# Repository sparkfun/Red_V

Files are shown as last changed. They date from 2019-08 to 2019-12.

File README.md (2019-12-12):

SparkFun RED-V RedBoard
============================

SparkFun RED-V RedBoard (https://www.sparkfun.com/products/15594)

*[SparkFun RED-V RedBoard (DEV-15594)](https://www.sparkfun.com/products/15594)*

The SparkFun RED-V (pronounced “red-five”) RedBoard is a low-cost, development board featuring the Freedom E310 SoC which brings with it the RISC-V instruction set architecture (ISA). What sets the RED-V RedBoard apart from the rest is the completely open-source approach from hardware to ISA. That means anyone can make full use the microcontroller without requiring royalties, licenses, or non-disclosure agreements. 

The RED-V RedBoard comes in the familiar Arduino Uno R3 form factor and includes the SiFive Freedom E310 core, 32MB of QSPI flash, an NXP K22 ARM Cortex-M4 for USB connectivity and operating as a JTAG interface, and a Qwiic connector to make I<sup>2</sup>C easy. The modern USB-C connector makes it easy to program and for more advanced users who prefer to use the power and speed of professional tools, we've also exposed the JTAG connector. Additionally, it comes programmed with a simple bootloader making the RED-V the best way to start prototyping and developing your RISC‑V applications. 

The on board Freedom E310 (FE310) is the first member of the Freedom Everywhere family of customizable SoCs from SiFive. Designed for microcontroller, embedded, IoT, and wearable applications, the FE310 features SiFive’s E31 CPU Coreplex, a high-performance, 32-bit RV32IMAC core. Running at 320+ MHz, the FE310 is among the fastest microcontrollers in the market. Additional features include a 16KB L1 Instruction Cache, a 16KB Data SRAM scratchpad, hardware multiply/divide, a debug module, flexible clock generation with on-chip oscillators and PLLs, and a wide variety of peripherals including UARTs, QSPI, PWMs, and timers. Multiple power domains and a low-power standby mode ensure a wide variety of applications can benefit from the FE310. The RED-V requires Freedom Studio software or a Zephyr RTOS build environment set up to program the board and interface with it.

Repository Contents
-------------------
* **/Hardware** - Eagle design files (.brd, .sch)
* **/Production** - Production panel files (.brd)

Documentation
--------------
* **[Hookup Guide](https://learn.sparkfun.com/tutorials/red-v-redboard-hookup-guide)** - Basic hookup guide for the RedBoard.
* **[RED-V Development Guide](https://learn.sparkfun.com/tutorials/red-v-development-guide)** - Getting started with the RED-V in Freedom Studio and Zephyr RTOS.

License Information
-------------------

This product is _**open source**_! 

Please review the LICENSE.md file for license information. 

If you have any questions or concerns on licensing, please contact techsupport@sparkfun.com.

Distributed as-is; no warranty is given.

- Your friends at SparkFun.

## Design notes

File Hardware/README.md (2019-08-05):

SparkFun Redboard Design Files
=====================================

The .sch and .brd files hare are Eagle CAD schematic and PCB design files from SparkFun Electronics.
A freeware version of Eagle can be found [here](http://www.cadsoftusa.com/download-eagle/freeware/).

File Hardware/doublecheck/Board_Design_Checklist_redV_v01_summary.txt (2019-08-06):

1) Is the I2C pull-up resistor isolation jumper present? [NO]
comment: exists on qwiic slaves

2) Is the MISO tri-state buffer included? [NO]
comment: copying risc-v schematic

3) Are all QFN components with 6 or more leads 75 percent pasted on lead pads? (May be contended depending on performance) [NO]
comment: 48 qfn is known good

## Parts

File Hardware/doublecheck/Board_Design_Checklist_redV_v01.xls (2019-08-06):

SECTION | CHECK | STATUS | DEPENDANCY | CORRECT ANSWER | USER | USER-ANSWER | COMMENT | WIKI_LINK
Macro | is_revision | 0
Macro | has_pth | 0
Macro | has_i2c | 1
Macro | has_SPI | 1
Macro | has_1x6_ftdi_header | 0
Macro | has_jumpers | 0
Macro | has_leds | 1
Macro | has_vreg | 1
Macro | has_QFN | 1
Macro | has_SS | 0
Macro | has_multi_sheet | 0
Macro | is_kit | 0
Macro | has_serial | 0
Macro | is_4layer | 0
Macro | has_milling | 0
Macro | has_switchorbutton | 1
Macro | has_collaboration | 0
Schematic | Does the board pass the Schematic Autochecklist ULP? |  |  | YES
Schematic | Are all schematic objects inside the frame? |  |  | YES | andrew.england | YES
Schematic | Is proper attribution given to the original designer? |  |  | YES | andrew.england | YES
Schematic | Is "Revised by: " and the reviser's name present? |  | 2 | YES | andrew.england | *n/a*
Schematic | Have all nets been drawn straight out from pin connections at least one grid space? |  |  | YES | andrew.england | YES
Schematic | Are there any 4-way junctions? |  |  | NO | andrew.england | NO
Schematic | Are junction dots used for all 3-wire connections? |  |  | YES | andrew.england | YES
Schematic | Are the fiducials in the lower right corner? |  |  | YES | andrew.england | YES
Schematic | Are the standoffs in the lower right corner? |  |  | YES | andrew.england | YES
Schematic | Are dashed grey lines ('info' eagle layer 97) used to clearly separate different areas? |  |  | YES | andrew.england | YES
Schematic | Is the version number correct? |  |  | YES | andrew.england | YES
Schematic | Is the version number included on all sheets? |  | 12 | YES | andrew.england | *n/a*
Schematic | Do all GND connections use the GND symbol (oriented downward)? |  |  | YES | andrew.england | YES
Schematic | Do all VCC connections use the VCC symbol (oriented upward)? |  |  | YES | andrew.england | YES
Schematic | Is the VCC range clearly labeled? |  |  | YES | andrew.england | YES
Schematic | Are any jumpers labeled clearly by their function and possible settings? |  | 7 | YES | andrew.england | *n/a*
Schematic | Are any appropriate warnings (voltage conversion, sensitive I/O) labeled? |  |  | YES | andrew.england | YES
Schematic | Are any notes of two versions of the board in the schematic (3.3V regulator vs 5V regulator)? |  |  | YES | andrew.england | n/a
Schematic | Do any part names have '/.~' in them? (Multiple sheets) |  | 12 | NO | andrew.england | *n/a*
Schematic | Have you verified that the BOM *including PCB* (also checking for PROD_ID, NAME, VALUE, PREFIX)? |  |  | YES | andrew.england | YES
Schematic | Do any parts have unnecessary values (Eagle has autoset the package as the value)? |  |  | NO | andrew.england | NO
Schematic | Regarding the voltage regulator, is the input on the LEFT, and the output on the RIGHT? |  | 9 | YES | andrew.england | YES
Schematic | Is the I2C address in the schematic? |  | 4 | YES | andrew.england | n/a
Schematic | Is the I2C pin order correct (GND/VCC/SDA/CLK) and did you consider using a Qwiic connector? |  | 4 | YES | andrew.england | YES |  | https://wiki.sparkfun.com/index.php?title=Eagle_Rules#Pin_Out.2FConnection_Orientation
Schematic | Is the I2C pull-up resistor isolation jumper present? |  | 4 | YES | andrew.england | NO | exists on qwiic slaves | https://wiki.sparkfun.com/index.php?title=Eagle_Rules#Component_Placement
Schematic | Is the SPI pull-up resistor for Chip Select present? |  | 5 | YES | andrew.england | YES |  | https://wiki.sparkfun.com/index.php?title=Eagle_Rules#Component_Placement
Schematic | Is the MISO tri-state buffer included? |  | 5 | YES | andrew.england | NO | copying risc-v schematic | https://wiki.sparkfun.com/index.php?title=Eagle_Rules#Component_Placement
Board | Does the board pass the Board Autochecklist ULP? |  |  | YES | andrew.england | YES |  | https://wiki.sparkfun.com/index.php?title=Qwiic_Standard
Board | If this board is not branded as a Qwicc board, but contains a Qwiic connector, is the connector labeled with “QWIIC” text silk? |  | 4 | YES | andrew.england | YES
Board | Are the inner layers on the correct eagle layers? (2 and 15) |  | 15 | YES | andrew.england | *n/a* |  | https://wiki.sparkfun.com/index.php?title=Eagle_Rules#Board_Creation.2C_Outline
Board | Does your 4 layer board include '1' '2' '3' '4' in the copper of each layer? |  | 15 | YES | andrew.england | *n/a* |  | https://wiki.sparkfun.com/index.php?title=Eagle_Rules#Board_Creation.2C_Outline
Board | If this is a Qwiic board, does it follow the design guidelines for Qwiic boards in the Wiki? |  | 4 | YES | andrew.england | n/a |  | https://wiki.sparkfun.com/index.php?title=Eagle_Rules#Board_Creation.2C_Outline
Board | If this requires very precise dimensions (e.g. USB stick), did you consider GP's tolerances? (dimension=5mils, Vscore=10mils) |  |  |  | andrew.england | YES |  | https://wiki.sparkfun.com/index.php?title=Eagle_Rules#Fab_house_Tolerances
Board | Do all testpoints have a separation of at least 0.1 inch (preferably placed on a 0.05 inch grid)? |  |  | YES | andrew.england | YES |  | https://wiki.sparkfun.com/index.php?title=Eagle_Rules#Board_Creation.2C_Outline
Board | Can standoffs/screws be used clear of other parts? |  |  | YES | andrew.england | YES |  | https://wiki.sparkfun.com/index.php?title=Eagle_Rules#Board_Creation.2C_Outline
Board | Is the FTDI connector accessible (do neighboring parts allow enough space to clear each side)? |  | 6 | YES | andrew.england | *n/a* |  | https://wiki.sparkfun.com/index.php?title=Eagle_Rules#Pin_Out.2FConnection_Orientation
Board | Is the FTDI connector oriented so the FTDI breakout can be slid on properly (IC side up, header side down)? |  | 6 | YES | andrew.england | *n/a* |  | https://wiki.sparkfun.com/index.php?title=Eagle_Rules#Pin_Out.2FConnection_Orientation
Board | Are vias tented correctly? |  |  | YES | andrew.england | YES |  | https://wiki.sparkfun.com/index.php?title=Eagle_Rules#Trace_Routing.2C_Polygon_Pours.2C_and_Vias
Board | If possible, are all overhanging parts on the same edge of the board (this helps with panelization)? |  |  | YES | andrew.england | YES |  | https://wiki.sparkfun.com/index.php?title=Eagle_Rules#Pin_Out.2FConnection_Orientation
Board | If this design requires special ordering or production assembly instructions, have the symbols/packages been added with notes? (PCB thickness, humidity sensitivity, etc.) |  |  | YES | andrew.england | NO
Board | Are any vias intended to be used as PTH headers (they shouldn't be)? |  |  | NO | andrew.england | NO |  | https://wiki.sparkfun.com/index.php?title=Eagle_Rules#Trace_Routing.2C_Polygon_Pours.2C_and_Vias
Board | Is the LED color standard followed? (red for power, blue for STAT, green for TX, yellow for RX) |  | 8 | YES | andrew.england | YES |  | https://wiki.sparkfun.com/index.php?title=Eagle_Rules#Component_Placement
Board | Do parts that need selective solder have a planned nozzle path on layer 48? (valid widths: 0.178", 0,263", 0.354") |  | 11 | YES | andrew.england | *n/a* |  | https://wiki.sparkfun.com/index.php?title=Eagle_Rules#Selective_Soldering
Board | As best as possible, do all SMD pads have only 1 trace entering the pad? |  |  | YES | andrew.england | YES |  | https://wiki.sparkfun.com/index.php?title=Eagle_Rules#PCB_Layout
Board | Are there any natural bridges on SMT components? |  |  | NO | andrew.england | NO |  | https://wiki.sparkfun.com/index.php?title=Eagle_Rules#PCB_Layout
Board | Do V-Scored edges have a 50 mil border free of pads and parts (to prevent cracking on separation)? |  |  | YES | andrew.england | YES
Board | Is the direction of TX/RX serial connections correct? |  | 14 | YES | andrew.england | *n/a*
Board | Are the TX/RX pins of the FTDI properly connected? |  | 6 | YES | andrew.england | *n/a*
Board | Is trace routing up to spec? (to/from center-points, straight lines, 45 angles, 'T' intersections, no right angles or acid traps) |  |  | YES | andrew.england | YES |  | https://wiki.sparkfun.com/index.php?title=Eagle_Rules#PCB_Layout
Board | For thermal considerations, are traces routed away from the component, with symmetrical routing? |  | 10 | YES | andrew.england | YES
Board | Do all footprints pass 1:1 check? (Applies mostly to new components) |  |  | YES | andrew.england | YES
Board | Are all QFN components with 6 or more leads 75 percent pasted on lead pads? (May be contended depending on performance) |  | 10 | YES | andrew.england | NO | 48 qfn is known good | https://wiki.sparkfun.com/index.php?title=Eagle_Rules#Footprints.2FPackages
Board | Are center pad cream apertures properly reduced? (50-75% paste is good) |  | 10 | YES | andrew.england | YES |  | https://wiki.sparkfun.com/index.php?title=Eagle_Rules#Footprints.2FPackages
Board | Is there solder mask between pads on of 11 mil separation and greater? |  |  | YES | andrew.england | YES |  | https://wiki.sparkfun.com/index.php?title=Eagle_Rules#Fab_house_Tolerances
Board | Is there a correct version number in the copper (aligned properly with the edge of the PCB)? |  |  | YES | andrew.england | YES
Board | Does it pass DRC with top/bottom keepout layers on? |  |  | YES | andrew.england | YES
Board | If there are any DRC errors, have they all been approved? |  |  | YES | andrew.england | YES
Board | Are all KIT PTH parts on the correct side with correct masking (e.g. the TSTOP or BSTOP expose the correct side) |  | 13 | YES | andrew.england | *n/a*
Documentation | Is there a note for a 4-layer board (on tDOCU)? |  | 15 | YES | andrew.england | *n/a*
Documentation | Do all packages have NAME and VALUE? |  |  | YES | andrew.england | YES
Documentation | Is there a note for a board thickness other than 0.63 inch? |  |  |  | andrew.england | NO
Documentation | Are measurements included for outer dimension and standoffs (Eagle layer 47)? |  |  | YES | andrew.england | YES
Documentation | Are the board dimensions on 0.05 inch or 0.01 inch grid? |  |  | YES | andrew.england | YES
Documentation | Are routed-out areas labeled 'ROUTE OUT' (on dimension)? |  | 16 | YES | andrew.england | *n/a*
Documentation | Is the designer name included in tDocu? |  |  | YES | andrew.england | YES
Documentation | Is 'Revised by:' and 'Revisor Name' included in tDocu? |  | 2 | YES | andrew.england | *n/a*
Silkscreen/Labeling | Is the name of the board on the board? |  |  | YES | andrew.england | YES |  | https://wiki.sparkfun.com/index.php?title=Eagle_Rules#PCB_Silk
Silkscreen/Labeling | Are all LEDs labeled with their purpose? |  | 8 | YES | andrew.england | YES
Silkscreen/Labeling | Are all PTHs (aka connectors) clearly labeled with their purpose on both sides of the board? |  |  | YES | andrew.england | n/a
Silkscreen/Labeling | Are battery terminals labeled +/- correctly? |  |  | YES | andrew.england | n/a
Silkscreen/Labeling | Are all jumpers labeled? |  | 7 | YES | andrew.england | *n/a*
Silkscreen/Labeling | If it is a 3-way jumper, is there a label on each side of the jumper? |  | 7 | YES | andrew.england | *n/a*
Silkscreen/Labeling | Are all switches/buttons labeled properly? |  | 17 | YES | andrew.england | YES
Silkscreen/Labeling | Are active low pins labeled clearly? |  |  | YES | andrew.england | YES
Silkscreen/Labeling | Are all labels lined up properly and legible? |  |  | YES | andrew.england | YES
Silkscreen/Labeling | Does the FTDI connector have BLK/GRN labeled correctly? |  | 6 | YES | andrew.england | *n/a*
Silkscreen/Labeling | Do all components have polarity or pin 1 labeled? |  |  | YES | andrew.england | YES
Silkscreen/Labeling | Is the polarity label outside of the package for visibility after part population? |  |  | YES | andrew.england | YES
Silkscreen/Labeling | Are there check labels for different versions of the board (3.3V vs 5V)? |  |  | YES | andrew.england | n/a
Silkscreen/Labeling | Is the firmware opensource? If not, did you omit the OSHW Logo? |  | 18 | YES | andrew.england | *n/a*
Silkscreen/Labeling | Is any silkscreen overlaid on vias? |  |  | NO | andrew.england | YES
Silkscreen/Labeling | Is there a URL for any kits or unique boards? |  |  |  | andrew.england | n/a
Special | Are dimension lines properly spaced for V-scoring (lines on a 0.020” center-to-center spacing)? |  |  |  | andrew.england | n/a
Special | On white solder mask pcbs, is there any solder mask between leads on large SMT components? |  |  |  | andrew.england | n/a
Special | Are axes labeled correctly? |  |  |  | andrew.england | n/a
Special | Are there warning labels for high voltage areas? |  |  |  | andrew.england | n/a
END | Thanks for flying with us. Have a great day!! |  |  |  | andrew.england | n/a

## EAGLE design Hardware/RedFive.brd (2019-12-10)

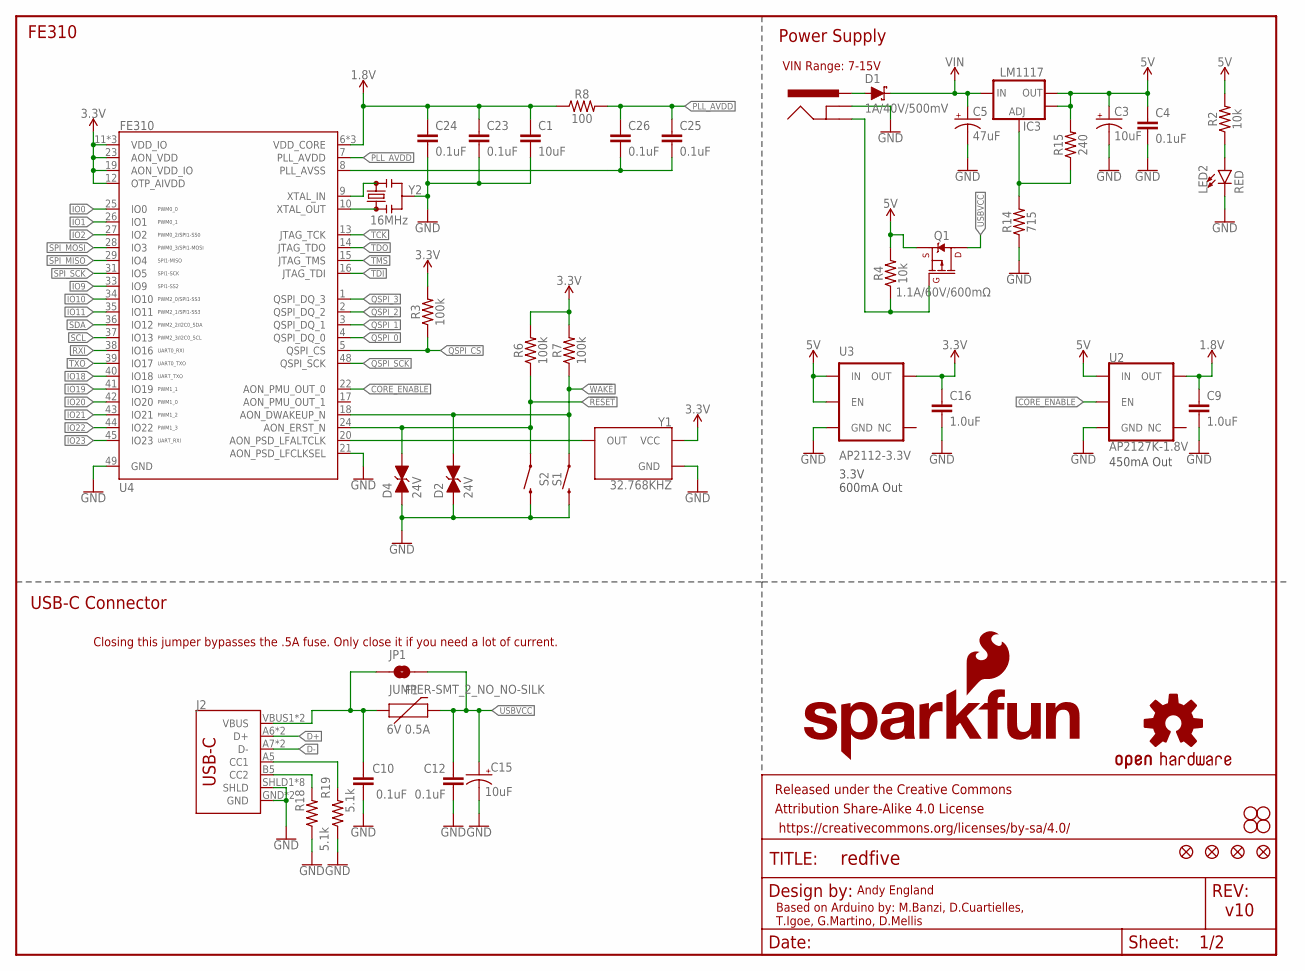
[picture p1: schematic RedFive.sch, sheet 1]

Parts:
C1: 10uF; 0603
C3, C15: 10uF; EIA3216
C4, C10, C12, C23, C24, C25, C26: 0.1uF; 0603
C5: 47uF; PANASONIC_D
C9, C16: 1.0uF; 0603
D1: 1A/40V/500mV; SMA-DIODE
D2, D4: 24V; 0603
F1: 6V 0.5A; 0805
FRAME2: FRAME-LETTER; CREATIVE_COMMONS
IC3: LM1117; SOT223-ALT1
J2: USB Female Type C Connector; USB-C-16P
J3: POWER_JACKSUPER_BOMB_DIGITY; POWER_JACK_SMD_OVERPASTE_SUPER_BOMB_DIGITY
JP1: JUMPER-SMT_2_NO_NO-SILK; SMT-JUMPER_2_NO_NO-SILK
JP3, JP4, JP5, JP6: STAND-OFF
JP8, JP9, JP15, JP16: FIDUCIAL1X2; FIDUCIAL-1X2
LED2: RED; LED-1206
LOGO1: SFE_LOGO_NAME_FLAME.1_INCH; SFE_LOGO_NAME_FLAME_.1
Q1: 1.1A/60V/600mΩ; SOT23-3
R2, R4: 10k; 0603
R3, R6, R7: 100k; 0603
R8: 100; 0603
R14: 715; 0603
R15: 240; 0603
R18, R19: 5.1k; 0603
S1, S2: MOMENTARY-SWITCH-SPST-SMD-6.2MM-TALL; TACTILE_SWITCH_SMD_6.2MM_TALL
U2: AP2127K-1.8V; SOT23-5
U3: AP2112-3.3V; SOT23-5
U4: FE310; QFN-48-.4MMPITCH
U$16: OSHW-LOGOS; OSHW-LOGO-S
Y1: 32.768KHZ; CRYSTAL-SMD-2X1.2MM
Y2: 16MHz; RESONATOR-SMD-3.2X1.3

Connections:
1.8V: C1.1, C9.1, C23.1, C24.1, R8.1, U2.5 (OUT), U4.6 (VDD_CORE), U4.30 (VDD_CORE), U4.46 (VDD_CORE)
3.3V: C16.1, R3.2, R6.2, R7.2, U3.5 (OUT), U4.11 (VDD_IO), U4.12 (OTP_AIVDD), U4.19 (AON_VDD_IO), U4.23 (AON_VDD), U4.32 (VDD_IO), U4.47 (VDD_IO), Y1.4 (VCC); also elsewhere on the board
5V: C3.+, C4.1, IC3.2 (OUT), IC3.4 (OUT), Q1.2 (S), R2.2, R4.2, R15.2, U2.1 (IN), U3.1 (IN), U3.3 (EN); also elsewhere on the board
!RESET: D4.2 (C), R6.1, S2.A2 (1), U4.24 (AON_ERST_N); also elsewhere on the board
!WAKE: D2.2 (C), R7.1, S1.A2 (1), U4.18 (AON_DWAKEUP_N); also elsewhere on the board
CORE_ENABLE: U2.3 (EN), U4.22 (AON_PMU_OUT_0)
D+: J2.A6 (D+), J2.B6 (D+); also elsewhere on the board
D-: J2.A7 (D-), J2.B7 (D-); also elsewhere on the board
GND: C1.2, C3.-, C4.2, C5.-, C9.2, C10.2, C12.2, C15.-, C16.2, C23.2, C24.2, D2.1 (A), D4.1 (A), J2.GND, J2.GND2 (GND), J2.SHLD1 (SHLD), J2.SHLD2 (SHLD), J2.SHLD3 (SHLD), J2.SHLD4 (SHLD), J2.SHLD5 (SHLD), J2.SHLD6 (SHLD), J2.SHLD7 (SHLD), J2.SHLD8 (SHLD), J3.GND (GNDBREAK), LED2.C, R14.1, R18.1, R19.1, S1.B2 (2), S2.B2 (2), U2.2 (GND), U3.2 (GND), U4.21 (AON_PSD_LFCLKSEL), U4.49 (GND), Y1.2 (GND), Y2.2; also elsewhere on the board
INSERT: J3.P$4 (GND), Q1.1 (G), R4.1
IO0: U4.25 (IO0); also elsewhere on the board
IO1: U4.26 (IO1); also elsewhere on the board
IO2: U4.27 (IO2); also elsewhere on the board
IO9: U4.33 (IO9); also elsewhere on the board
IO10: U4.34 (IO10); also elsewhere on the board
IO11: U4.35 (IO11); also elsewhere on the board
IO18: U4.40 (IO18); also elsewhere on the board
IO19: U4.41 (IO19); also elsewhere on the board
IO20: U4.42 (IO20); also elsewhere on the board
IO21: U4.43 (IO21); also elsewhere on the board
IO22: U4.44 (IO22); also elsewhere on the board
IO23: U4.45 (IO23); also elsewhere on the board
unnamed: LED2.A, R2.1
unnamed: U4.10 (XTAL_OUT), Y2.1
unnamed: U4.9 (XTAL_IN), Y2.3
unnamed: U4.20 (AON_PSD_LFALTCLK), Y1.3 (OUT)
unnamed: C25.2, C26.2, U4.8 (PLL_AVSS)
unnamed: J2.B5 (CC2), R18.2
unnamed: IC3.1 (ADJ), R14.2, R15.1
unnamed: J2.A5 (CC1), R19.2
PLL_AVDD: C25.1, C26.1, R8.2, U4.7 (PLL_AVDD)
PWRIN: D1.A, J3.VIN0 (PWR)
QSPI_0: U4.4 (QSPI_DQ_0); also elsewhere on the board
QSPI_1: U4.3 (QSPI_DQ_1); also elsewhere on the board
QSPI_2: U4.2 (QSPI_DQ_2); also elsewhere on the board
QSPI_3: U4.1 (QSPI_DQ_3); also elsewhere on the board
QSPI_CS: R3.1, U4.5 (QSPI_CS); also elsewhere on the board
QSPI_SCK: U4.48 (QSPI_SCK); also elsewhere on the board
RXI: U4.38 (IO16); also elsewhere on the board
SCL: U4.37 (IO13); also elsewhere on the board
SDA: U4.36 (IO12); also elsewhere on the board
SPI_MISO: U4.29 (IO4); also elsewhere on the board
SPI_MOSI: U4.28 (IO3); also elsewhere on the board
SPI_SCK: U4.31 (IO5); also elsewhere on the board
TCK: U4.13 (JTAG_TCK); also elsewhere on the board
TDI: U4.16 (JTAG_TDI); also elsewhere on the board
TDO: U4.14 (JTAG_TDO); also elsewhere on the board
TMS: U4.15 (JTAG_TMS); also elsewhere on the board
TXO: U4.39 (IO17); also elsewhere on the board
USBVCC: C12.1, C15.+, F1.2, JP1.2, Q1.3 (D)
VIN: C5.+, D1.C, IC3.3 (IN); also elsewhere on the board
VUSB: C10.1, F1.1, J2.VBUS1 (VBUS), J2.VBUS2 (VBUS), JP1.1

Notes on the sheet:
Power Supply
FE310
USB-C Connector
Based on Arduino by: M.Banzi, D.Cuartielles, T.Igoe, G.Martino, D.Mellis
Andy England
v10
VIN Range: 7-15V
3.3V 600mA Out
450mA Out
Closing this jumper bypasses the .5A fuse. Only close it if you need a lot of current.

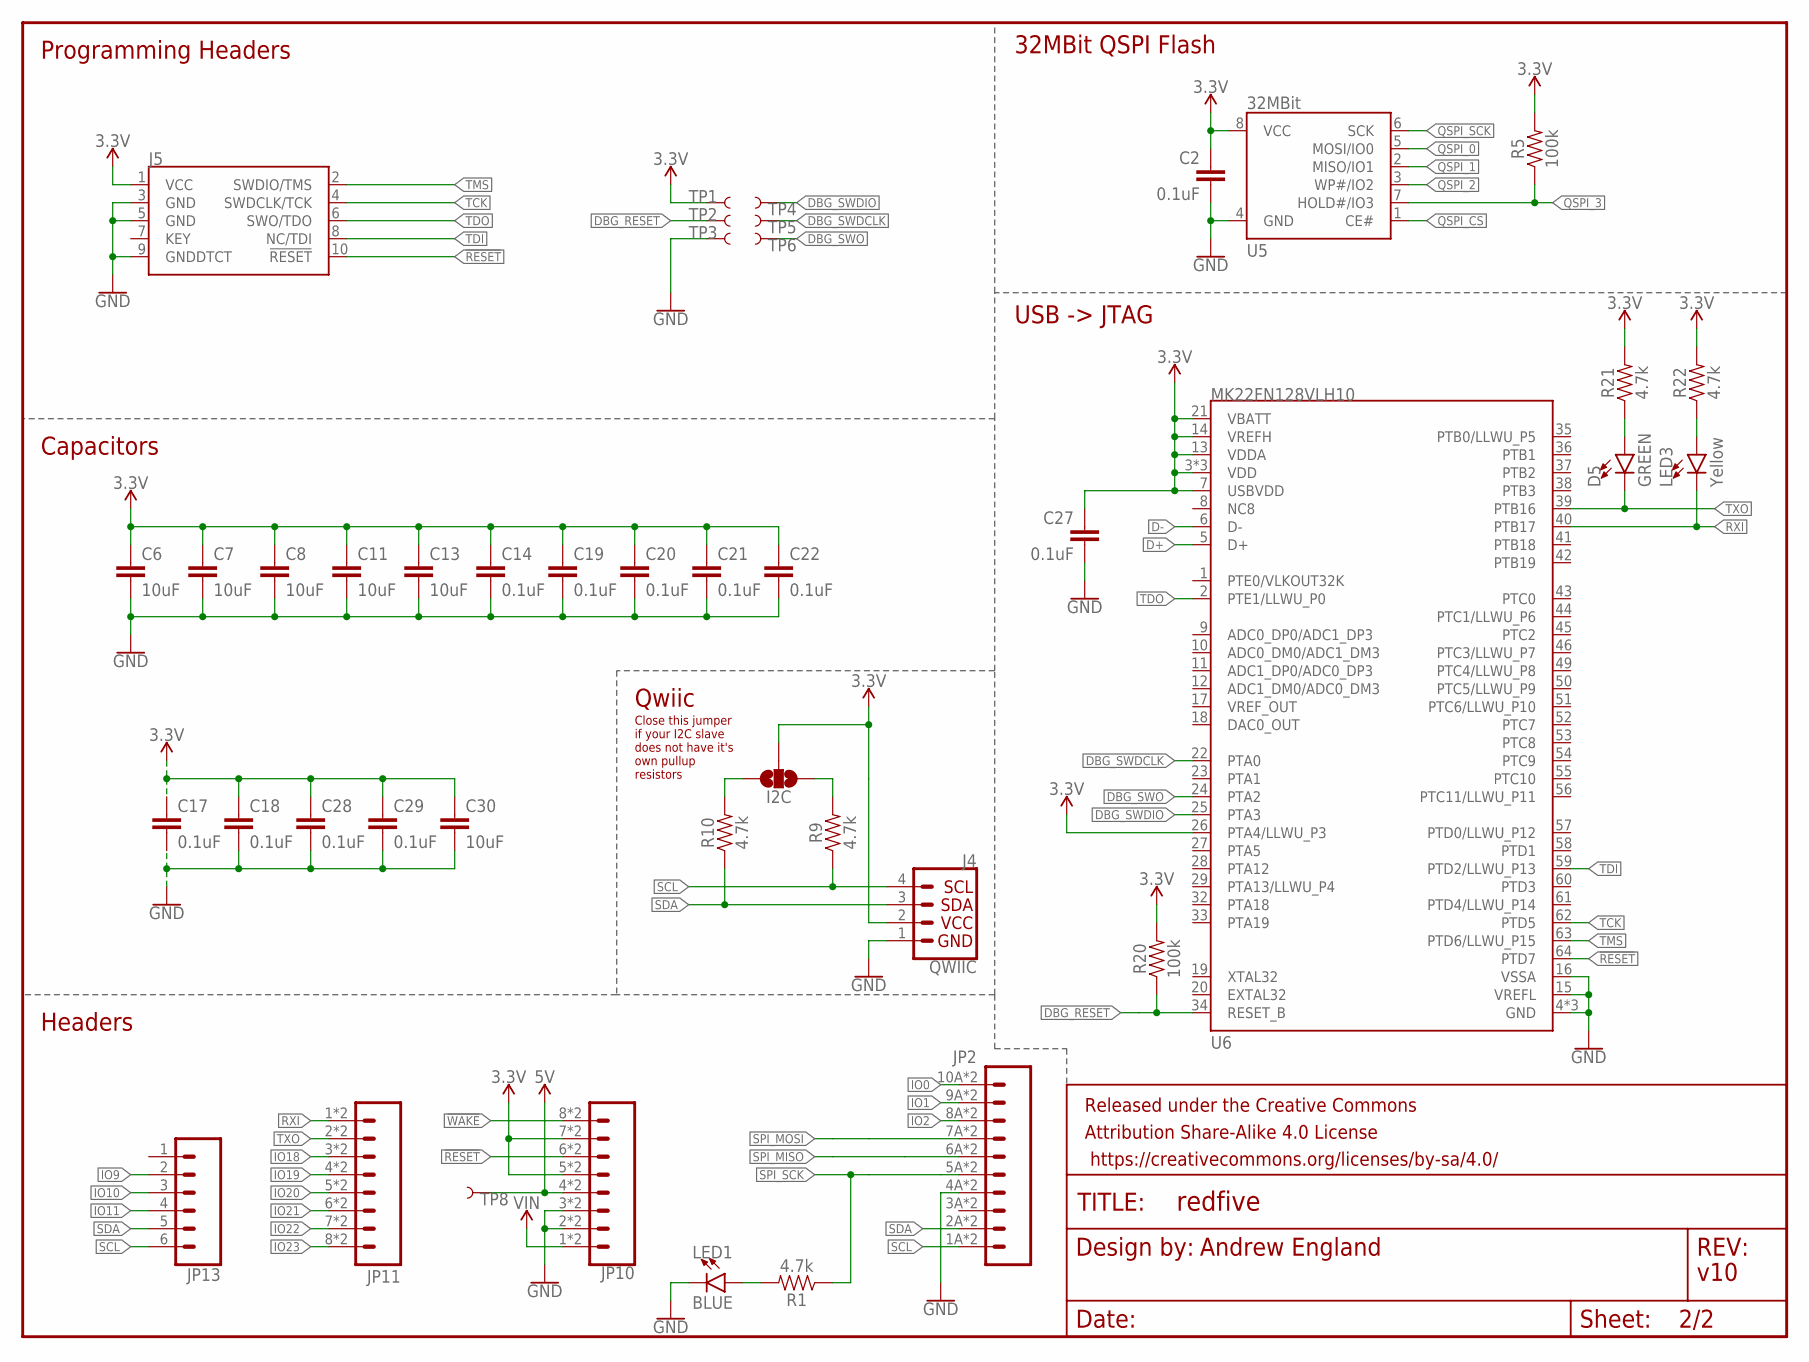
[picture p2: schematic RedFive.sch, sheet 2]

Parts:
C2, C14, C17, C18, C19, C20, C21, C22, C27, C28, C29: 0.1uF; 0603
C6, C7, C8, C11, C13, C30: 10uF; 0603
D5: GREEN; LED-1206
FRAME1: FRAME-LETTER; CREATIVE_COMMONS
I2C: JUMPER-SMT_3_NO_NO-SILK; SMT-JUMPER_3_NO_NO-SILK
J4: QWIIC; JST04_1MM_RA
J5: CORTEX_JTAG_DEBUG_PTH_NS; 2X5-PTH-1.27MM-NO_SILK
JP2: CONN_10SMD_COMBO-FEMALE; 1X10_SMD_COMBINED
JP10: CONN_08SMD-COMBO-FEMALE; 1X08_SMD_COMBINED
JP11: JP11; 1X08_SMD_COMBINED
JP13: CONN_06SMD-STRAIGHT-COMBO-FEMALE; 1X06_SMD_STRAIGHT_COMBO
LED1: BLUE; LED-1206
LED3: Yellow; LED-1206
R1, R9, R10, R21, R22: 4.7k; 0603
R5, R20: 100k; 0603
TP1, TP2, TP3, TP4, TP5, TP6: TEST-POINT3X5; PAD.03X.05
TP8: TEST-POINT3; PAD.03X.03
U5: 32MBit; SO08
U6: MK22FN128VLH10; LQFP-64

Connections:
3.3V: C2.1, C6.1, C7.1, C8.1, C11.1, C13.1, C14.1, C17.1, C18.1, C19.1, C20.1, C21.1, C22.1, C27.1, C28.1, C29.1, C30.1, I2C.2, J4.2, J5.1 (VCC), JP10.5, JP10.5@2 (5), JP10.7, JP10.7@2 (7), R5.2, R20.2, R21.2, R22.2, TP1.P$1, U5.8 (VCC), U6.3 (VDD), U6.7 (USBVDD), U6.13 (VDDA), U6.14 (VREFH), U6.21 (VBATT), U6.26 (PTA4/LLWU_P3), U6.30 (VDD), U6.48 (VDD); also elsewhere on the board
5V: JP10.4, JP10.4@2 (4), TP8.P$1; also elsewhere on the board
!RESET: J5.10 (!RESET), JP10.6, JP10.6@2 (6), U6.64 (PTD7); also elsewhere on the board
!WAKE: JP10.8, JP10.8@2 (8); also elsewhere on the board
D+: U6.5 (D+); also elsewhere on the board
D-: U6.6 (D-); also elsewhere on the board
DBG_RESET: R20.1, TP2.P$1, U6.34 (RESET_B)
DBG_SWDCLK: TP5.P$1, U6.22 (PTA0)
DBG_SWDIO: TP4.P$1, U6.25 (PTA3)
DBG_SWO: TP6.P$1, U6.24 (PTA2)
GND: C2.2, C6.2, C7.2, C8.2, C11.2, C13.2, C14.2, C17.2, C18.2, C19.2, C20.2, C21.2, C22.2, C27.2, C28.2, C29.2, C30.2, J4.1, J5.3 (GND), J5.5 (GND), J5.9 (GNDDTCT), JP2.4A (4), JP2.4B (4), JP10.2, JP10.2@2 (2), JP10.3, JP10.3@2 (3), LED1.C, TP3.P$1, U5.4 (GND), U6.4 (GND), U6.15 (VREFL), U6.16 (VSSA), U6.31 (GND), U6.47 (GND); also elsewhere on the board
IO0: JP2.10A (10), JP2.10B (10); also elsewhere on the board
IO1: JP2.9A (9), JP2.9B (9); also elsewhere on the board
IO2: JP2.8A (8), JP2.8B (8); also elsewhere on the board
IO9: JP13.2; also elsewhere on the board
IO10: JP13.3; also elsewhere on the board
IO11: JP13.4; also elsewhere on the board
IO18: JP11.3, JP11.3@2 (3); also elsewhere on the board
IO19: JP11.4, JP11.4@2 (4); also elsewhere on the board
IO20: JP11.5, JP11.5@2 (5); also elsewhere on the board
IO21: JP11.6, JP11.6@2 (6); also elsewhere on the board
IO22: JP11.7, JP11.7@2 (7); also elsewhere on the board
IO23: JP11.8, JP11.8@2 (8); also elsewhere on the board
unnamed: LED1.A, R1.2
unnamed: I2C.3, R10.2
unnamed: I2C.1, R9.2
unnamed: LED3.A, R22.1
unnamed: D5.A, R21.1
QSPI_0: U5.5 (MOSI/IO0); also elsewhere on the board
QSPI_1: U5.2 (MISO/IO1); also elsewhere on the board
QSPI_2: U5.3 (WP#/IO2); also elsewhere on the board
QSPI_3: R5.1, U5.7 (HOLD#/IO3); also elsewhere on the board
QSPI_CS: U5.1 (CE#); also elsewhere on the board
QSPI_SCK: U5.6 (SCK); also elsewhere on the board
RXI: JP11.1, JP11.1@2 (1), LED3.C, U6.40 (PTB17); also elsewhere on the board
SCL: J4.4, JP2.1A (1), JP2.1B (1), JP13.6, R9.1; also elsewhere on the board
SDA: J4.3, JP2.2A (2), JP2.2B (2), JP13.5, R10.1; also elsewhere on the board
SPI_MISO: JP2.6A (6), JP2.6B (6); also elsewhere on the board
SPI_MOSI: JP2.7A (7), JP2.7B (7); also elsewhere on the board
SPI_SCK: JP2.5A (5), JP2.5B (5), R1.1; also elsewhere on the board
TCK: J5.4 (SWDCLK/TCK), U6.62 (PTD5); also elsewhere on the board
TDI: J5.8 (NC/TDI), U6.59 (PTD2/LLWU_P13); also elsewhere on the board
TDO: J5.6 (SWO/TDO), U6.2 (PTE1/LLWU_P0); also elsewhere on the board
TMS: J5.2 (SWDIO/TMS), U6.63 (PTD6/LLWU_P15); also elsewhere on the board
TXO: D5.C, JP11.2, JP11.2@2 (2), U6.39 (PTB16); also elsewhere on the board
VIN: JP10.1, JP10.1@2 (1); also elsewhere on the board

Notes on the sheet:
Qwiic
Headers
Programming Headers
32MBit QSPI Flash
Capacitors
Andrew England
v10
USB -> JTAG
Close this jumper if your I2C slave does not have it's own pullup resistors

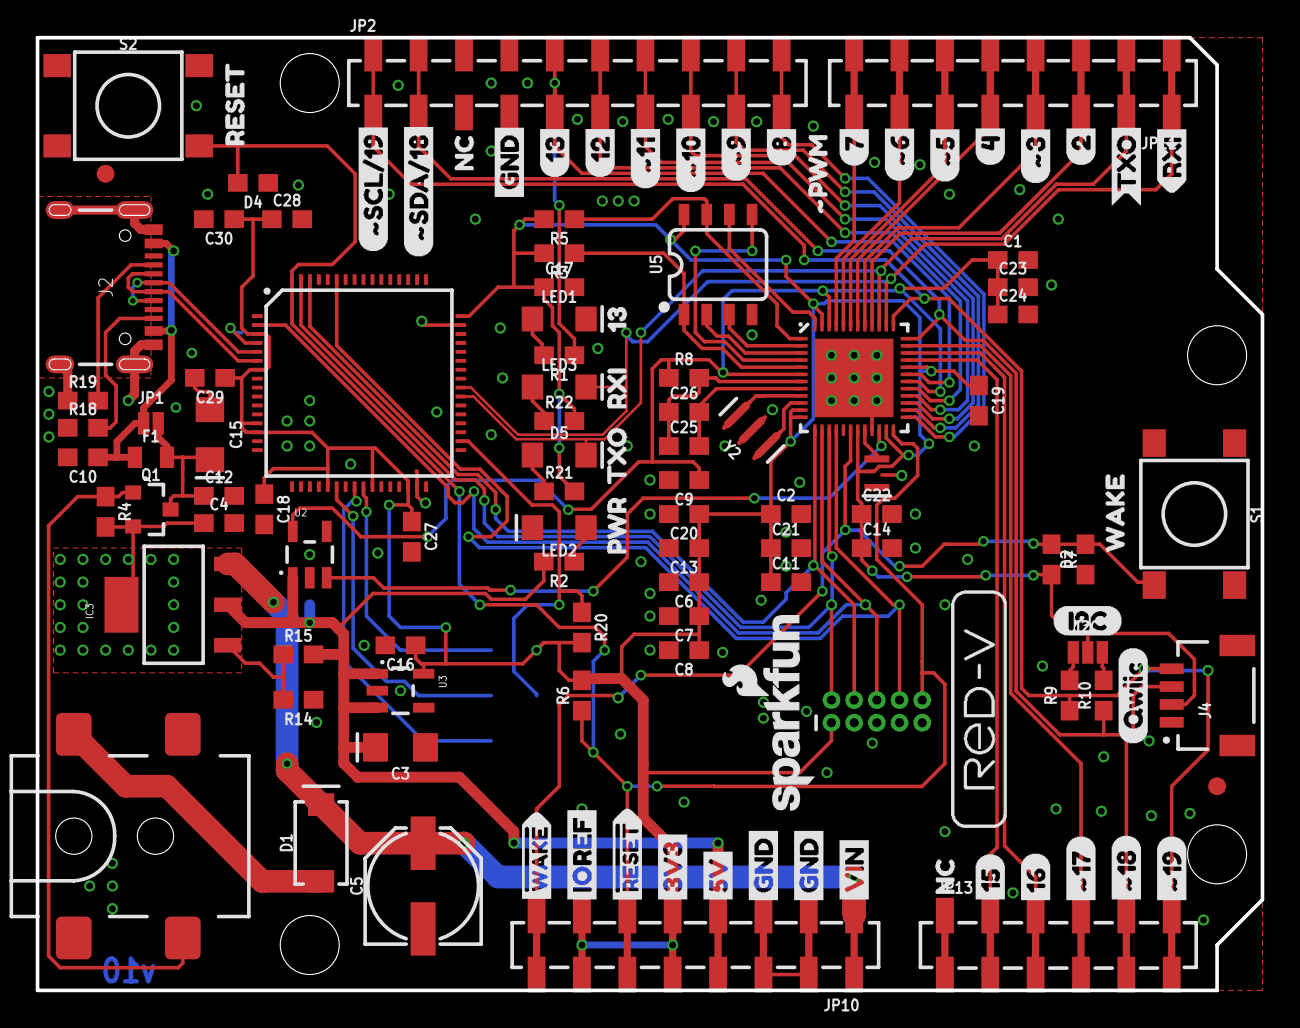
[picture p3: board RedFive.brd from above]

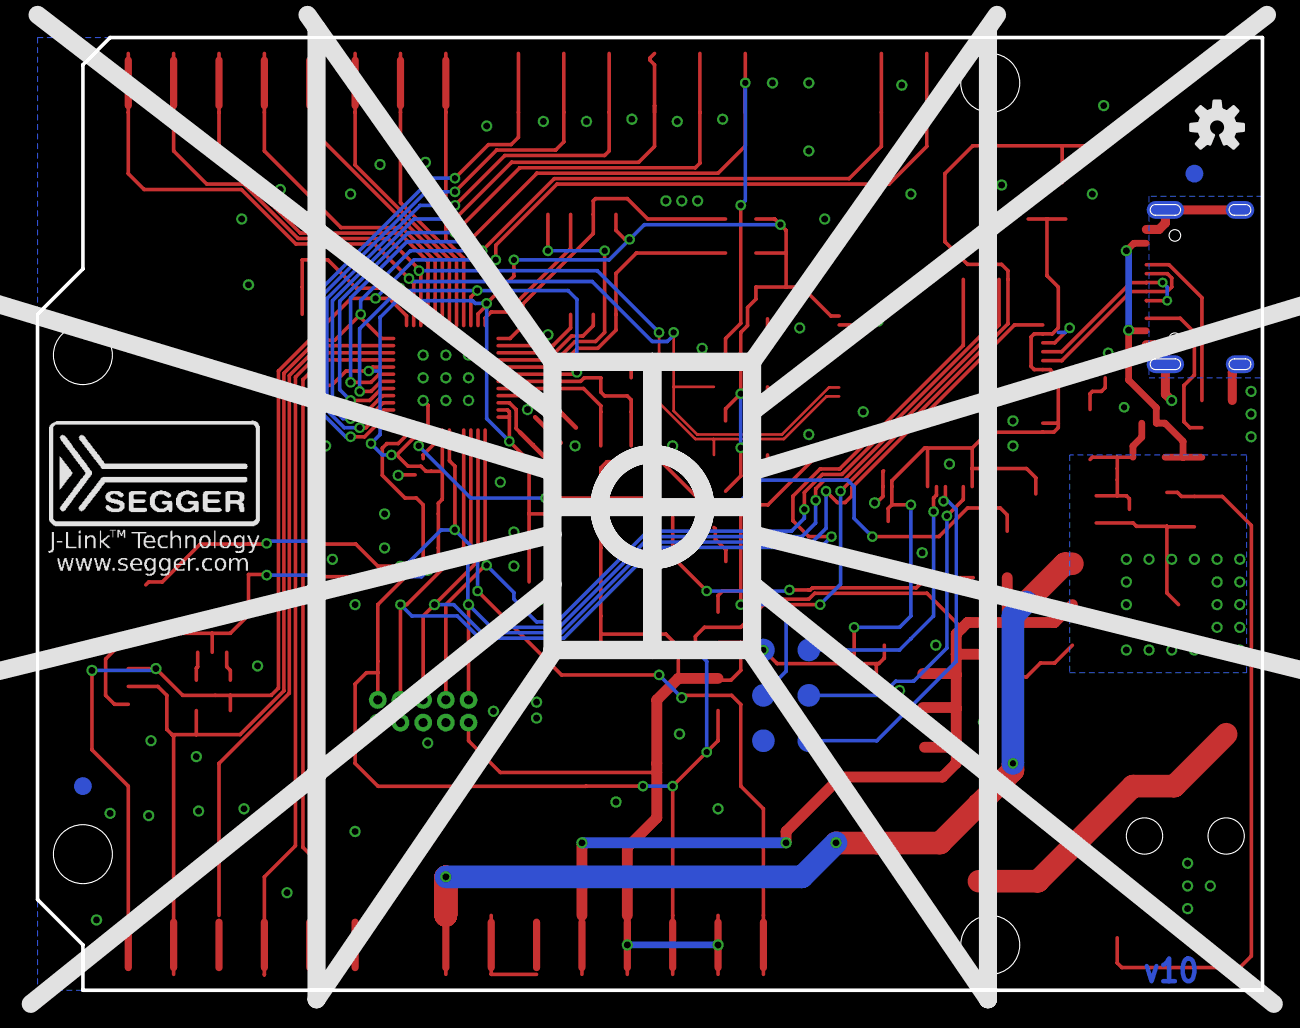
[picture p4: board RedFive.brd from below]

Board: 2 copper layers, 68.6 x 53.3 mm, 138 parts (11 on the bottom side), 61 nets.

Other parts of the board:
U$1: (QWIIC)
U$2: #324
U$3: #522
U$4: #621
U$8: SEGGERLOGO#PNG
U$9: #918
U$11: I2C0
U$14: #1017
U$15: #1116
U$17: #1710
U$18: #1812
U$19: #1911
U$20: #RESET2
U$21: #SCL#1926
U$22: #SDA#1827
U$23: #WAKE0
U$24: 3V33
U$25: 5V4
U$26: 158
U$27: 169
U$28: 225
U$29: 423
U$30: 720
U$31: 819
U$32: 1215
U$33: 1314
U$34, U$35, U$36: GND5
U$37: IOREF1
U$38, U$43: NC7
U$39: RXI29
U$40: TXO28
U$41: VIN6
U$42: _#PWM30
U$45: 133
U$46: PWR0
U$47: RXI1
U$48: TXO2
U$49: RESET0
U$50: WAKE1
U$52: REDFIVE_LOGO#05#PNG

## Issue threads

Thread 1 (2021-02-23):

Red-V board is not 'open source'

PE1NUT, 2021-02-23:
To quote the README.md of this repository, and the text on the Sparkfun website:

'What sets the RED-V RedBoard apart from the rest is the completely open-source approach from hardware to ISA. That means anyone can make full use the microcontroller without requiring royalties, licenses, or non-disclosure agreements.'

However, the USB/JTAG interface is a proprietary, closed-source product from SEGGER, and requires installation of their software to fully support it. The documentation on the Sparkfun website states: 'Warning: Do NOT attempt to reprogram the NXP K22 ARM Cortex-M4. It has proprietary Segger firmware flashed onto the chip, which allows it to upload programs to the SiFive Freedom E310 core. Reprogramming the NXP K22 ARM Cortex-M4 will overwrite the firmware and you will no longer be able to reprogram the board. To replace the firmware, you will need to purchase a license from Segger along with one of their programmers.'

So much for not requiring 'royalties, licenses'.

Furthermore, the source code (or even the binaries) of the Red-V firmware are not included in this repository. One cannot study or modify the code of this 'open source' device. If you accidentally write to the flash chip (as I did), there is no way to restore it - the SEGGER software requires purchasing an additional license to upload my backup to the flash chip.

jrddunbr, 2022-01-31:
I came to this repository looking exactly for this sort of comment.

Has anyone written alternative open source firmware for the NXP chip? All it really needs to do is tell the FE310 to write data to the QSPI flash so that the FE310 can boot from it, right? (lol that's  not as easy as it sounds, I know)

[Looking at the schematic for the board](https://cdn.sparkfun.com/assets/d/d/1/e/7/RedFive.pdf), it looks like the NXP chip is connected to the FE310's JTAG port, but only the FE310 can talk to the QSPI flash - so it's not as easy as just writing a USB-to-QSPI flash program; at least I don't think so. Maybe it just needs to be modified over the memory map?

I've had one of these boards collecting dust in my parts bin for a long time now. I would love to see an open source firmware tool so that everything on this board is end-to-end open source. You would think they would have everything open source/hardware on a development board that runs an open source ISA...

chaoyangnz, 2023-07-13:
@PE1NUT do you still have a backup? I did the same and now my program at 0x2001000 can not be running after reset.

could you share your backup to me?

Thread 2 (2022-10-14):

The schematic in Sparkfun is not correct

romancardenas, 2022-10-14:
I found an issue with the [board schematic](https://cdn.sparkfun.com/assets/d/d/1/e/7/RedFive.pdf). According to this schematic, the blue LED is connected to the GPIO5. However, this is not true, and the correct GPIO is the 13.

romancardenas, 2022-10-14:
Ok, so this is what it happened: pin 5 corresponds to digital output 13. So... The schematic is correct, but the naming of the digital inputs is a bit confusing. I'll close the issue.

Closed 2022-10-14.

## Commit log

2019-08-05 initial layout for proto
    [RedFive.brd, RedFive.sch]
2019-08-06 pre review changes
    [RedFive.brd, RedFive.sch]
2019-08-06 post review changes
    [RedFive.brd, RedFive.sch]
2019-08-06 design review checklist
    [Board_Design_Checklist_redV_v01.xls, RedFive.brd, RedFive.sch]
2019-08-06 ordered prototypes
    [RedFive.GBL, RedFive.GBO, RedFive.GBS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]
2019-08-14 Adding prod_id to JTAG
    [RedFive.brd, RedFive.sch]
2019-08-22 pre design review number 2
    [RedFive.brd, RedFive.sch]
2019-08-22 small schematic tweaks, thanks pete for notes
    [RedFive.brd, RedFive.sch]
2019-08-22 post design review changes
    [RedFive.brd, RedFive.sch]
2019-08-22 post checklist changes, protos ordered
    [RedFive.brd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]
2019-09-18 updating Gerbers to v02 with NXP chip
2019-09-27 adding 5V test point
    [RedFive.brd, RedFive.sch]
2019-10-09 needs routing, post prototype changes
    [RedFive.brd, RedFive.sch]
2019-10-16 Pre design review-reds
    [RedFive.brd, RedFive.sch]
2019-10-16 post review changes-v10
    [RedFive.brd, RedFive.sch]
2019-10-16 post checklist changes
    [RedFive.brd, RedFive.sch]
2019-12-10 updating R8 to 100 Ohm
    [RedFive.brd, RedFive.sch]

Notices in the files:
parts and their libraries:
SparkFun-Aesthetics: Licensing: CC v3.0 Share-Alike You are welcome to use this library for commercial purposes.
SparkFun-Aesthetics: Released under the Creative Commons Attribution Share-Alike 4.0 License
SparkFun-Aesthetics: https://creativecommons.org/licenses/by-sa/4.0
